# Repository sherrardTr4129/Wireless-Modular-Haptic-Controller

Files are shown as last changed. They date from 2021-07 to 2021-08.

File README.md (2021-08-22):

# Wireless-Modular-Haptic-Controller
A small, flexible and modular wireless haptic controller for mobile manipulator control. This project attempts to take the rudimentary controller design implemented [here](https://github.com/sherrardTr4129/RealSense-BNO055-Pose-Estimation), and add a more complex feature set. Multiple controllers can be used on the same mesh network to create more intuitive human-robot interfaces. Ultimately, the goal of this project is to create a configuration of controllers to provide dexterous control of a mobile manipulator system. 

## Demo Video
Have a look at the system in action! The video below shows a single controller being used for controlling the locobot base with adaptive scaling control. 

LoCoBot Control (https://www.youtube.com/watch?v=vkgRInzt20c)

## Single Controller Architecture
A given single controller offers much more sensing and actuation capability as compared to the controller design implemented [here](https://github.com/sherrardTr4129/RealSense-BNO055-Pose-Estimation). In this design, each controller acts as a node on a larger mesh network. This allows for ease of addition and subtraction of nodes from said network, depending on the desired HRI configuration. Each controller has the ability to deliver audio (including basic TTS) and vibrotactile feedback to the user. In addition, the controller still contains a BNO055 sensor to extract the orientation of the controller itself in three dimensional space. Each given controller also has two momentary push buttons for user input. Please see the figure below for a graphical depicition of the controller architecture. 

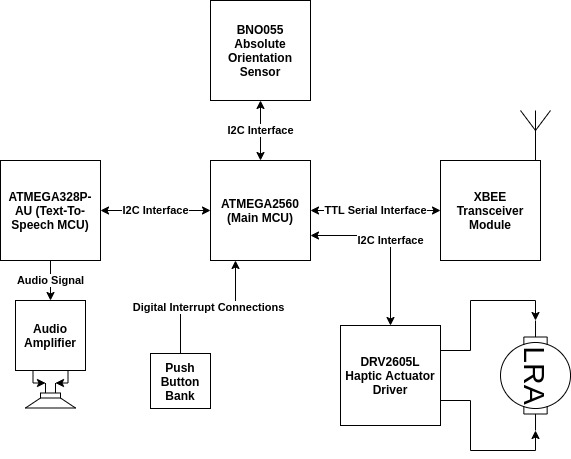
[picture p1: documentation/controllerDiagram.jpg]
Controller Architecture Diagram


The table below contains a more in-depth explaination of the individual controller architecture, including each sub-system's components.

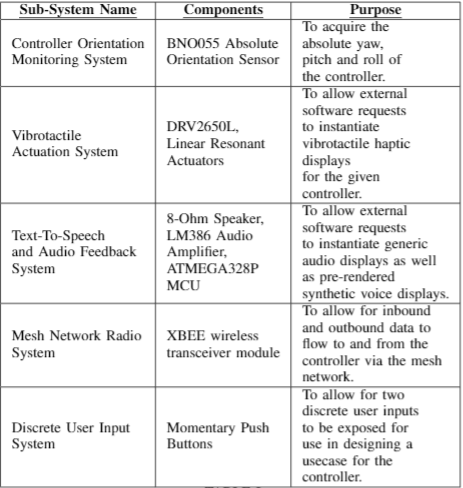
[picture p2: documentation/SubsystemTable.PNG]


The individual controller's firmware was designed using a split application level firmware and board support package (BSP) paradigm. All sensor and actuator control drivers were contained within the BSP and could be accessed from a BSP instance within the application level firmware. A graphical depiction of this software architecture can be seen within the figure below.

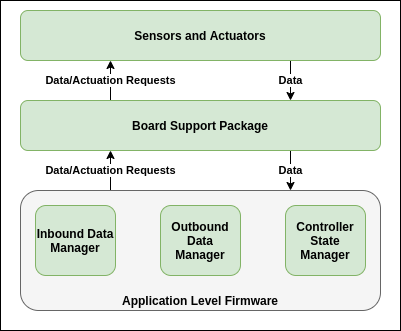
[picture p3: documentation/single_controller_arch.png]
Controller Software Architecture Diagram


Once the controller is completely assembled, it should look something like the controller in the figure below. 

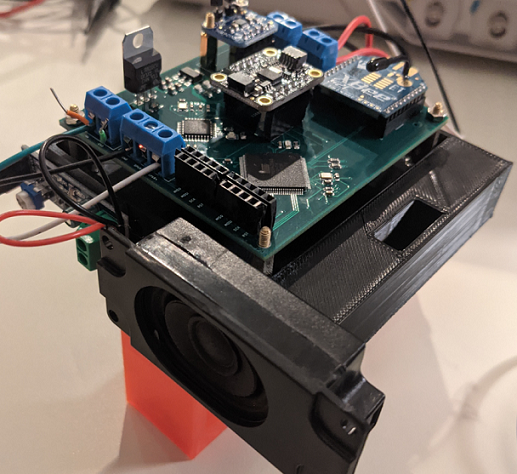
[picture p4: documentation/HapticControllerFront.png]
Controller Build


## High Level System Architecture
The system is comprised of a single base-station node, and several controller nodes. The base-station node serves as the entry point into the network and coordinates the setup of the overall mesh network (coordinator node). A ROS driver manages data transactions between the ROS infrastructure and the controller mesh network via a serial interface with the coordinator node. The mesh network itself is comprised of wireless XBee modules attached to each controller. These provide a high level of configurability for a relatively low price. Have a look at the data flow diagram below for a simplified explanation of the system's base configuration. 

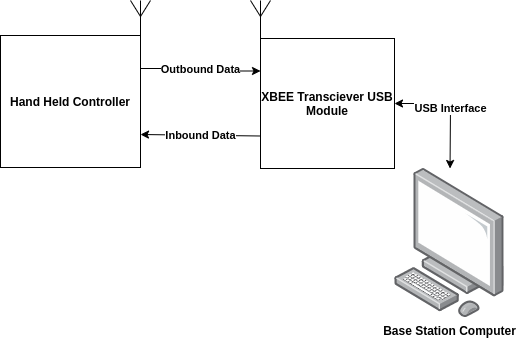
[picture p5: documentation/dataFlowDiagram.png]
Data Flow Diagram


A brief explanation of the inbound and outbound data types referenced in the above diagram can be seen in the table below.

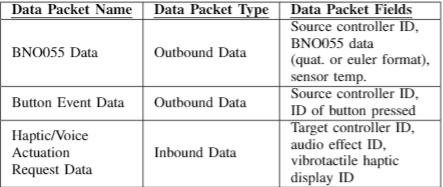
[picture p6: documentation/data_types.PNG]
Data Types


More controller nodes can be added to the network as needed based on the desired human-robot interface configuration. All data is transmitted in broadcast mode. That is, each node on the network will recieve data transmitted from any individual node. This was done to avoid having to set up direct addressing, and thus increasing the flexibility and ease of setup for the system. Data packets transmitted from a given node are formatted in JSON. One of the JSON fields in any given data packet format is the desired recipient of the data packet. This allows nodes on the network to quickly discern whether to process a given data packet or not using the aforementioned broadcast transmission mode.

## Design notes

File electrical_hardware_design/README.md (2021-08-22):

# Electrical Hardware Design
This sub-directory contains the KiCAD project used to generate the GERBERs needed to manufactor the PCB for the haptic controller. An overview of the PCB design and system BoM can be seen in the sections below.

## PCB Design
The PCB for the controller itself was attempted to be designed to be as modular as possible. For example, each of the sensors and actuators can be dynamically populated and de-populated based on the needs of the given controller within the HRI configuration being constructed. Please note that the PCB was designed with the assumption that it would be manufactored through the use of JLCPCB, so many of the surface mount components are chosen from their inventory system. A picture of the bare PCB can be seen in the image below. 

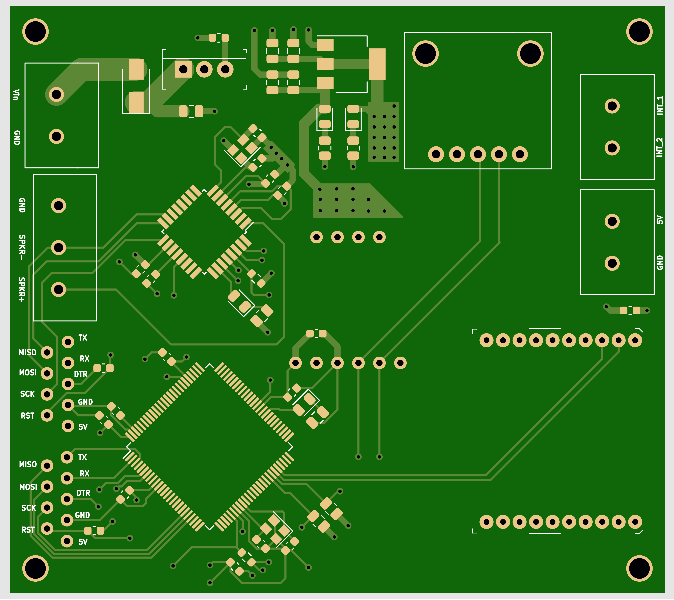
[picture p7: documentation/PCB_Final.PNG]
Bare PCB


The overall controller is powered off of a 9V battery, but can handle input voltages up to 12V. Some of the other electical charictoristics of the controller can be seen within the table in the figure below.

Electrical Charictoristics

## System Bill Of Materials
The overall bill of materials needed to build a single controller can be seen within the table below.

| Item | Vendor Link | Price Per Unit | Quantity  | Total Price |
|:---:|:---:|:---:|:---:|:---:|
| XBee Transceivers | [Link](https://www.digikey.com/en/products/detail/digi/XB24CZ7WIT-004/5322374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) | $27.93 | 1 | $27.93 |
| DRV2605L | [Link](https://www.adafruit.com/product/2305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) | $7.95 | 1 | $7.95 |
| ERM Pancake Motor | [Link](https://www.adafruit.com/product/1201) | $1.95 | 1 | $1.95 |
| 0.5W 8Ohm Speaker | [Link](https://www.sparkfun.com/products/15350) | $0.95 | 1 | $0.95 |
| Momentary Push Buttons (Pack Of 10) | [Link](https://www.amazon.com/weideer-Momentary-Self-Reset-Pre-soldered-R13-507-RBK-X/dp/B08SQQWJ5X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) | $1.00 | 1 | $1.00 |
| Stemma BNO055 Breakout | [Link](https://www.adafruit.com/product/4646) | $19.95 | 1 | $19.95 |
| PCB (populated) | N/A | $15 | 1 | $15 |
| L7805CV | [Link](https://www.amazon.com/L7805CV-Positive-Voltage-Regulator-Output/dp/B09B2D3T2F) | $0.40 | 1 | $0.40 |
| LM386 Breakout | [Link](https://www.amazon.com/gp/product/B01FDD3FYQ/ref=ppx_yo_dt_b_asin_title_o00_s00?ie=UTF8&psc=1) | $1.598 | 1 | $1.598 |
| Screw Terminals | [Link](https://www.amazon.com/gp/product/B07H5G7GC6/ref=ppx_yo_dt_b_asin_title_o09_s00?ie=UTF8&psc=1) | $0.17 | 4 | $0.67 |
| Misc Consumables (standoffs, pin headers) | N/A | $2 | 1 | $2 |
| | | | | |
| | | | Total Cost: | $79.39 |

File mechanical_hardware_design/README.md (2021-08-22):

# Mechanical Hardware Design
The mechanical designs for this project were designed under a modularity paradigm. That is, the base that the controller PCB is installed in is designed to be attached to a hand-held controller, haptic belt, or other mounting location depending on the desired HRI configuration. In addition to the controller base, a hand-held glove was also designed to allow for easy interfacing with the controller itself. The controller base and hand-held glove assembly (with push buttons installed) can be seen in the figure below.

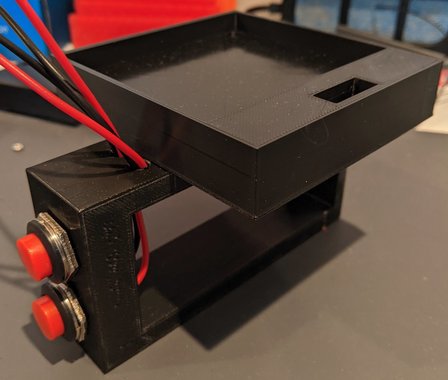
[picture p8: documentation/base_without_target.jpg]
Controller Assembly


The controller base is designed to allow for an optional vision target to be installed. This vision target will allow for the extraction of the controller's position in 3D space to be extracted through the use of a depth camera. Please have a look at the figure below depicting the controller base and hand-held glove assembly (with push buttons installed) along with the optional vision target.

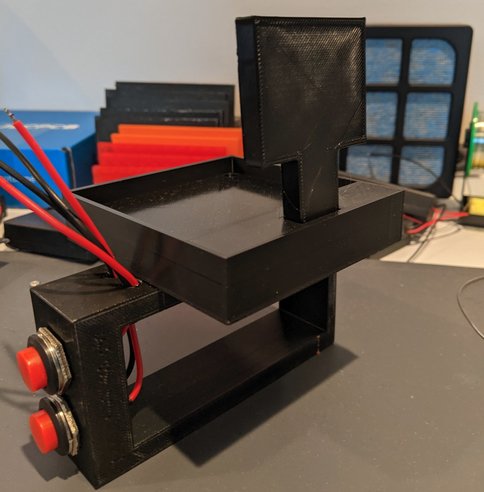
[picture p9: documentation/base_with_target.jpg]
Controller Assembly With Vision Target


The mechanical designs for these three aforementioned mechanical components can be found in the folders within the sub-directory as freeCAD documents. You can export the STL to 3D print these components from freeCAD.

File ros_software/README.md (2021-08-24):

# ROS Software
This sub-directory outlines the ROS software developed to showcase the capabilities of the modular haptic controller. In particular, this sub-directory includes a ROS driver for bi-directional interfacing with the controller network via standard ROS interfaces. It also included a ROS package that interfaces with said ROS driver to demonstrate the control of a robot base using the controller in its hand-held configuration. 

## Inbound and Outbound Data Packet JSON Formats
This sub-section outlines the JSON schema for the inbound and outbound data packets for a given controller on the controller mesh network.

### Outbound data JSON schema
The format of outbound BNO055 data packets can be seen below (if usingEuler is set to true):
```JSON
{
  "packet_type": "outbound_data",
  "controller_id": "right_hand",
  "euler_x": 0,
  "euler_y": 0,
  "euler_z": 0,
  "temp_c": 30
}
```

If usingEuler is set to false, the format of the outbound BNO055 data packet will be:
```JSON
{
  "packet_type": "outbound_data",
  "controller_id": "right_hand",
  "quat_x": 0,
  "quat_y": 0,
  "quat_z": 0,
  "quat_w": 0,
  "temp_c": 30
}
```

Note these are both just templates, and the value of a given field will change.

The other outbound data type from a given controller is event data packets. These are transmitted whenever user input is obtained through the pushbuttons attached to a given controller. The format of this type of data packet can be seen below:
```JSON
{
  "packet_type": "button_event",
  "controller_id": "right_hand",
  "event_type": "top_button_pressed"
}
```

### Inbound data JSON schema
Inbound JSON data packets contain a target controller, and a requested audio or haptic event to display to the user. These data packets take the form of the following JSON schema:

```JSON
{
  "controller_name": "right_hand",
  "voice_action_id": 1,
  "haptic_action_id": 53
}
```

More on the meanings of the values for the voice\_action\_id and haptic\_action\_id fields in the upcomming sections. The JSON seen above will be created within the ROS driver itself, so don't worry too much about this.

## ROS Coordinator Node Serial Driver
The haptic\_orientation\_capture\_driver ROS node serves as a bridge between the controller mesh network and a given ROS software architecture. This driver will manage the serial interfacing between a base-station coordinator XBee and the host computer. This driver will also publish recieved BNO055 data streams and button press events. This driver also exposes a ROS service that can be called by external ROS nodes to send audio-haptic event requests to a given controller on the mesh network. 

### Custom Messages
The packages outlined here make use of a few custom ROS messages to communicate between the ROS infrustructure and the controller mesh network. Please have a look at the table below for an outline of these messages.

| Message Name | Message Components |
|---|---|
| bno055_euler_data.msg | **Description** - BNO055 data received from mesh network is published to ROS infrastructure through this message (euler format) <br><br>**Message Content:**<br>string controller\_name - The controller the BNO055 data came from<br>Header header - header containing a timestamp<br>float64 roll - roll data (in degrees)<br>float64 pitch - pitch data (in degrees)<br>float64 yaw - yaw data (in degrees) |
| bno055_quat_data.msg | **Description** - BNO055 data received from mesh network is published to ROS infrastructure through this message (quaternion format)<br><br>**Message Content:**<br>string controller\_name - The controller the BNO055 data came from<br>geometry_msgs/QuaternionStamped quat - orientation data as quaternion |
| controller_event_data.msg | **Description** - button press event data received from mesh network is published to ROS infrastructure through this message<br><br>**Message Content:**<br>string controller\_name - The controller the button event data came from<br>Header header - header containing a timestamp<br>string event_type - string representation of which button was pressed on the controller |
| controller_haptic_voice.msg | **Description** - audio-haptic requests can be sent to a given controller on the mesh network via the ROS service described below. <br>This message is used to make said request.<br><br>**Message Content:**<br>string controller\_name - The controller the request is bound for<br>int16 haptic_action_id - selected haptic display ID<br>int16 voice_action_id - selected TTS display ID |

### Custom Service
The haptic\_orientation\_capture\_driver ROS node hosts a service that allows users to request an audio-haptic event to be performed by a given controller. This service call requires a haptic\_voice\_event message instance containing the voice\_action\_id and haptic\_action\_id for a given controller with name controller\_name. For the pre-rendered TTS events, please see firmware to determine mapping between voice\_action\_id and a given TTS event. For the haptic diplays, haptic\_action\_id should be chosen from the table below based on the desired waveform.

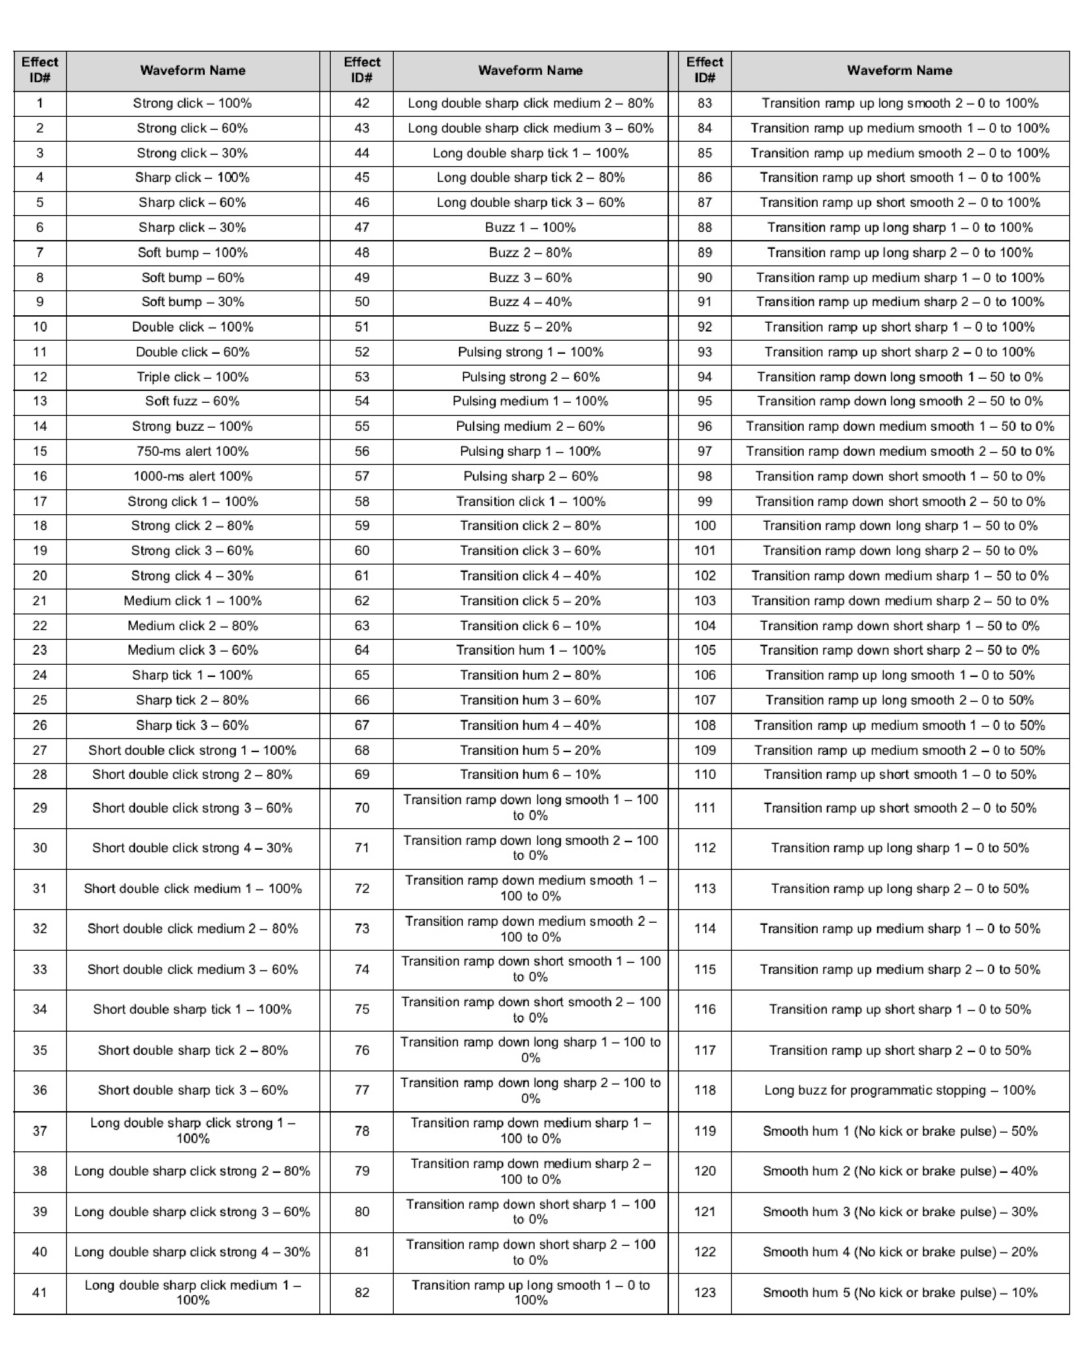
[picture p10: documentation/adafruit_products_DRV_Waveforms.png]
DRV2560 Waveforms


## LoCoBot Base Control Example
The locobot\_haptic\_control ROS package was developed to showcase the usefulness of the developed modular controller. This particular node makes use of all the data streams available from a controller, and can make audio-haptic requests based on custom conditions set by the user. Currently, the node allows for control of the robot base with adjustable scaling. The scaling mode can be changed through button press events on the controller. Please see the youtube video in this repositories base README.md file for an example of this working. Both the haptic\_orientation\_capture\_driver and the locobot\_haptic\_control ROS packages can be launched using the locobot\_haptic\_control.launch file in the locobot\_haptic\_control ROS package.

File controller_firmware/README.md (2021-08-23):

# Controller Firmware Design
This sub-directory contains the firmware developed for the two processors on the hand-held controller. Please see below for notes about each MCU's firmware and the procedure to flash the firmware onto each of the MCU's. 

## Firmware Dependencies 
This section will breifly outline the different firmware dependencies within this project. Please note that all firmware dependencies are obtainable through the arduino software manager. 

### Main Controller Firmware Dependencies
* **Adafruit Sensor Library** - This library provides general functionallity required for the two onboard adafruit sensors.
* **Adafruit BNO055 Library** - This library provides functionallity needed to read data from the onboard BNO055 sensor via an I2C interface. 
* **Adafruit DRV2605 Library** - This library provides functionallity needed to interface with the DRV2605 driver board via an I2C interface.
* **ArduinoJson** - This library provides JSON document construction functionallity and functionallity to serialize said documents via the XBee wireless interface. 

### Text-To-Speech Controller Firmware Dependencies
* **Talkie** - This library provides rudimentary TTS functionallity utilizing the onboard MCU TIMER1 and TIMER2 peripherals. 

## Main Controller Firmware
The main controller firmware is designed to run on the ATMEGA2560 processor on the PCB. Its main purpose is to actuate audio-haptic displays based on requests received by the basestation, and to transmit data from the onboard BNO055 sensor back to the basestation. Outside of the main\_controller\_firmware.ino file, two other software packages are provided. The first is the BSP, which provides functionallity required to initialize and manage all onboard actuators and sensors. The second is the inbound and outbound data stream managers. These classes are designed to unpack incomming request JSON packets from the basestation and package and serialize BNO055 data JSON packets respectively. 

For each controller on the network, two lines of code need to be examined and potentially changed at compile time within the main\_controller\_firmware.ino file. The first is:

```C
bool usingEuler = true;
```
This boolean flag will setup the BNO55 sensor in euler angle mode if true, and quaternion mode if false. The outbound JSON document will be set up differently depending on the state of this variable as well. The second line to examine is:

```C
const char* controller_name = "right_hand";
```
This line defines the given controller's name. The controller name is an important field in all inbound and outbound JSON packets. For outbound data, the controller\_name field is used to determine the origin of the recieved BNO055 data packet. For inbound data, the recieved data packet needs to have the controller\_name field value equivalent to the name set in the above line of code for it to be processed by a given controller. Please ajdust this line accordingly based on the desired HRI configuration.

## Text-To-Speech Controller Firmware
The Text-To-Speech controller firmware is designed to be run on the ATMEGA328P-AU processor on the PCB. It's main purpose is to accept requests to play pre-rendered TTS audio events via the I2C interface managed by the main controller. The I2C transaction is simple, as it requires a single integer number between 0 and 4 corresponding to one of the aforementioned TTS events. The TTS events are instantiated through the use of the Talkie library. If the included vocabularies within the Talkie library do not suit your needs, there are [tutorials](https://github.com/ptwz/python_wizard) on how to render new TTS events.

## Bootloader and Firmware Flashing Proceedure
The pins on the PCB itself needed to flash the bootloader and respective firmware can be seen highlighted in the image below:

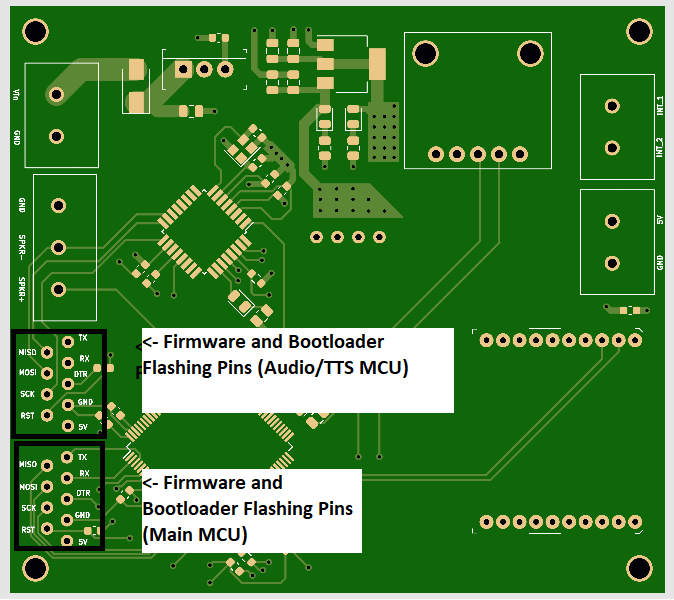
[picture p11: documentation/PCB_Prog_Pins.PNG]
MCU Bootloader and Firmware Flashing Pins


### Bootloader Flashing 
After assembling a new board mechanically and electrically, the appropriate bootloader needs to be flashed to each respective MCU. The easist way to do this is to use a seperate arduino uno as an ICSP device. Please follow the tutorial outlined [here](https://www.electronics-lab.com/project/installing-the-arduino-bootloader-on-the-atmega328p-microcontroller/) to flash the bootloader onto each respective MCU using an arduino uno as an ICSP. Please note that this tutorial assumes the target chip is an ATMEGA328P, which is true for the TTS MCU, but not for the main MCU. Make sure to change the board type to "ATmega2560" when flashing the bootloader to the main MCU.

### Firmware Flashing
To flash the firmware on each respective MCU, a USB->TTL Serial converter is required. I made use of the converter found [here](https://www.amazon.com/HiLetgo-FT232RL-Converter-Adapter-Breakout/dp/B00IJXZQ7C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) In my development efforts. In the case of either MCU, the connections between the USB->TTL Serial converter and the board need to be made as described below:

| Firmware Flashing Pin | USB<->TTL Serial Converter Pin |
|---|---|
| GND | GND |
| TX | RX |
| RX | TX |
| DTR | DTR (through 100nF capacitor)  |

Please make sure to change the programmer from "Arduino as ISP" used in the last step back to "AVRISP MKll" before trying to upload any firmware.

## XBee Radio Configuration
As mentioned previously, the controller XBees all need to be configured as routers, and the single base-station XBee needs to configured as a coordinator. In all cases, the devices should be set in broadcast mode. That is, if a packet is transmitted from an XBee radio, all other radios on the network should recieve it. There are several tutorials on XBee configuration using the XTCU tool. [Here](https://youtu.be/cf3RLBg4t5s) is one useful tutorial video.

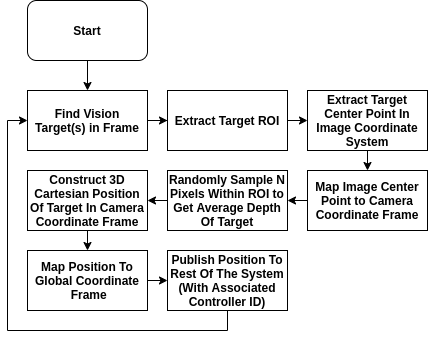
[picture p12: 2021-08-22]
documentation/coordinate_extraction_process.png

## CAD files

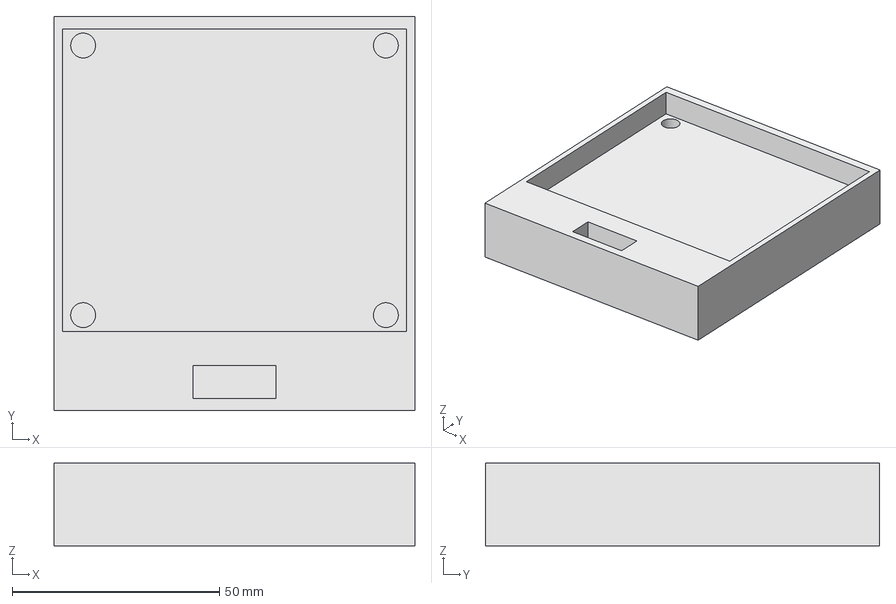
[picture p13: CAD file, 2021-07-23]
mechanical_hardware_design/controller_holder/controller_board_holder.FCStd
87.0 x 95.0 x 20.0 mm

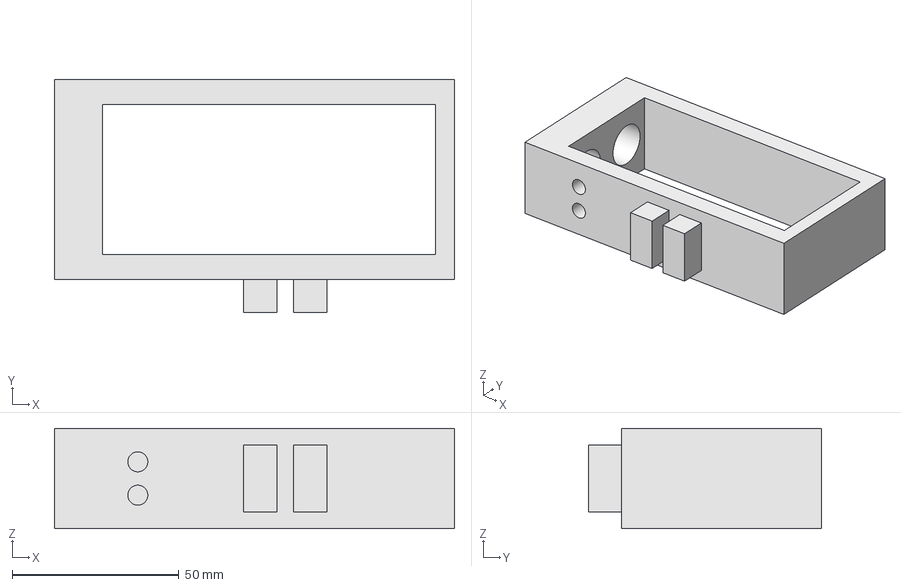
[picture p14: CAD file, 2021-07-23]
mechanical_hardware_design/hand_glove/hand_glove_base.FCStd
120.0 x 70.0 x 30.0 mm

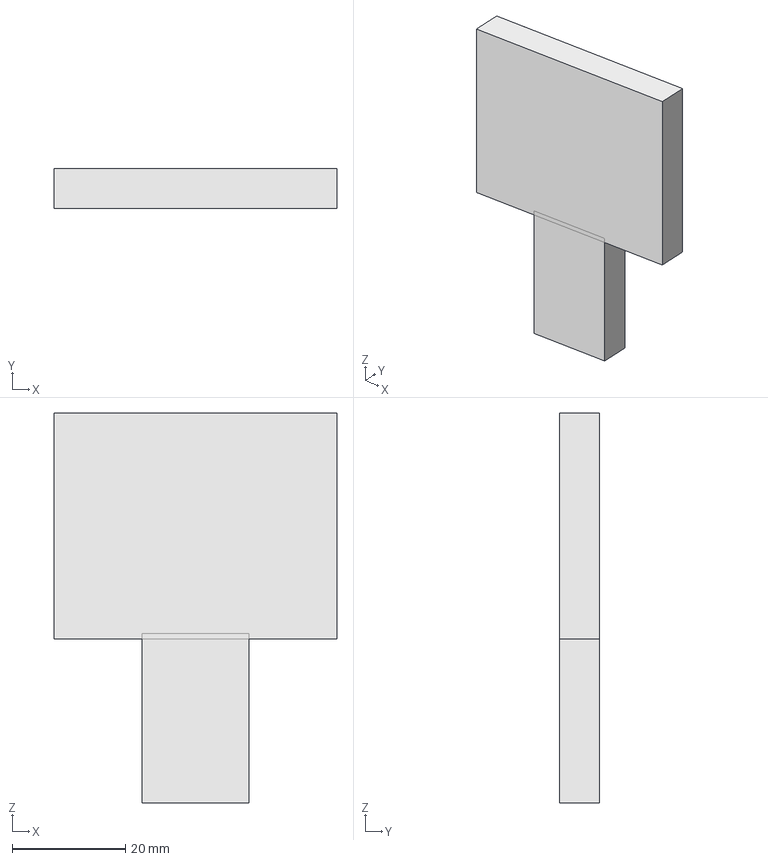
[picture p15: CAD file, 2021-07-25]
mechanical_hardware_design/vision_target/vision_target.FCStd
50.0 x 7.00 x 69.0 mm

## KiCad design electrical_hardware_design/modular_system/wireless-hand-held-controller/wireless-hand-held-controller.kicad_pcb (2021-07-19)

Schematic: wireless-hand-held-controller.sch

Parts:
C1, C4: 4.7u; C_0805_2012Metric; LCSC C1779
C2: 330n; C_0805_2012Metric; LCSC C1740
C3, C7: 1u; C_0805_2012Metric; LCSC C28323
C5, C6, C8, C9, C10, C13, C16, C17, C18, C19, C20, C21, C22, C23, C24: 100n; C_0603_1608Metric; LCSC C14663
C11, C12, C14, C15: 15p; C_0603_1608Metric; LCSC C1644
D1: D_Small; D_SMA; LCSC C95872
D2, D3, D4, D5: LED; LED_0805_2012Metric; LCSC C84256
J1: 328P_Prog_Pins; fivePinConn
J2: 328P_Bootloader_Pins; fourPinConn
J3: Input Power; 2-pinScrewTerm
J4: 2560_Prog_Pins; fivePinConn
J5: 2560_Bootloader_Pins; fourPinConn
J6: Speaker Conn; 3-pinScrewTerminal
J7: INT_PWR_CON; 2-pinScrewTerm
J8: External_Interrupts; 2-pinScrewTerm
MOD1: XB24CZ7WIT-004; XBEE-20_THT; MPN XB24CZ7WIT-004; Digi-Key_PN 602-1560-ND
Q1, Q2: BSS138; SOT-23-3; MPN BSS138; Digi-Key_PN BSS138CT-ND
R1, R3, R4, R6, R7, R8: 4.7k; R_0805_2012Metric; LCSC C17673
R2, R5: 10k; R_0603_1608Metric; LCSC C25804
R9, R10, R11, R12: 10k; R_1206_3216Metric; LCSC C17902
U1: L7805CV; TO-220-3; MPN L7805CV; Digi-Key_PN 497-1443-5-ND
U2: AMS1117-3.3; SOT-223-3_TabPin2; LCSC C6186
U3: ATmega328P-AU; TQFP-32_7x7mm_P0.8mm; LCSC C14877
U4: ATmega2560-16AU; TQFP-100_14x14mm_P0.5mm; LCSC C22460
U5: StemmaBNO055
U6: DRV2605L
Y1, Y2: 16Mhz; Crystal_SMD_2520-4Pin_2.5x2.0mm; LCSC C284159

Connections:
328P_MISO_CON: J2.4, U3.16 (PB4)
328P_MOSI_CON: J2.3, J6.2, U3.15 (PB3)
328P_RESET_CON: C13.1, J2.1, R2.1, U3.29 (~RESET~/PC6)
328P_RX_CON: J1.4, U3.30 (PD0)
328P_SCK_CON: J2.2, U3.17 (PB5)
328P_TX_CON: J1.5, U3.31 (PD1)
328P_XTAL1_CON: C11.1, U3.7 (XTAL1/PB6), Y1.1
328P_XTAL2_CON: C12.1, U3.8 (XTAL2/PB7), Y1.3
2560_MISO_CON: J5.4, U4.22 (PB3)
2560_MOSI_CON: J5.3, U4.21 (PB2)
2560_RESET_CON: C17.1, J5.1, R5.1, U4.30 (~RESET)
2560_RX_CON: J4.4, U4.2 (PE0)
2560_SCK_CON: J5.2, U4.20 (PB1)
2560_SCL_CON: R8.2, U3.28 (PC5), U4.43 (PD0), U5.4 (SCL), U6.3 (SCL)
2560_SDA_CON: R6.2, U3.27 (PC4), U4.44 (PD1), U5.5 (SDA), U6.4 (SDA)
2560_TX_CON: J4.5, U4.3 (PE1)
2560_XTAL1_CON: C14.1, U4.34 (XTAL1), Y2.1
2560_XTAL2_CON: C15.1, U4.33 (XTAL2), Y2.3
+3V3: C4.1, C7.1, C23.1, D3.2 (A), MOD1.1 (Vcc), Q1.1, Q2.1, R9.2, R10.2, U2.2 (VO)
+5V: C1.1, C3.1, C5.1, C8.1, C9.1, C10.1, C18.1, C19.1, C20.1, C21.1, C22.1, C24.2, D2.2 (A), J1.1, J4.1, J7.2, R2.2, R5.2, R6.1, R8.1, R11.2, R12.2, U1.3 (OUT), U2.3 (VI), U3.4 (VCC), U3.6 (VCC), U3.18 (AVCC), U4.10 (VCC), U4.31 (VCC), U4.61 (VCC), U4.80 (VCC), U4.100 (AVCC), U5.1 (Vin), U6.1 (Vin)
+BATT: C2.1, D1.1 (K), U1.1 (IN)
GND: C1.2, C2.2, C3.2, C4.2, C5.2, C6.2, C7.2, C8.2, C9.2, C10.2, C11.2, C12.2, C14.2, C15.2, C16.2, C18.2, C19.2, C20.2, C21.2, C22.2, C23.2, C24.1, J1.2, J3.1, J4.2, J6.3, J7.1, MOD1.10 (GND), R1.1, R3.1, R4.1, R7.1, U1.2 (GND), U2.1 (GND), U3.3 (GND), U3.5 (GND), U3.21 (GND), U4.11 (GND), U4.32 (GND), U4.62 (GND), U4.81 (GND), U4.99 (GND), U5.3 (GND), U6.2 (GND), Y1.2, Y1.4, Y2.2, Y2.4
INT1_CON: J8.2, U4.6 (PE4)
INT2_CON: J8.1, U4.7 (PE5)
unnamed: C6.1, U3.20 (AREF)
unnamed: C13.2, J1.3
unnamed: C16.1, U4.98 (AREF)
unnamed: C17.2, J4.3
unnamed: D1.2 (A), J3.2
unnamed: D2.1 (K), R1.2
unnamed: D3.1 (K), R3.2
unnamed: D4.1 (K), R4.2
unnamed: D5.1 (K), R7.2
unnamed: D5.2 (A), U4.59 (PC6)
SPKR_NON_INVERTING: J6.1, U3.1 (PD3)
TALKING_STATUS: D4.2 (A), U3.26 (PC3)
XBEE_RX_3.3V: MOD1.3 (DIN/~Config), Q1.2, R10.1
XBEE_RX_5V: Q1.3, R11.1, U4.46 (PD3)
XBEE_TX_3.3V: MOD1.2 (DOUT), Q2.2, R9.1
XBEE_TX_5V: Q2.3, R12.1, U4.45 (PD2)

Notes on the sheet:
ATMEGA328P-AU programming connections
ATMEGA328P-AU MCU Oscillator
Indicator LEDs
input power
Power Rail Regulation
ATMEGA2560 Programming/Bootloader Flash
ATMEGA2560 MCU Oscillator
ATMEGA328P-AU MCU
i2c bus
BNO055 Sensor
DRV2605L Haptic Driver
XBEE
Connections For External Interrupts
XBEE Level Shifting

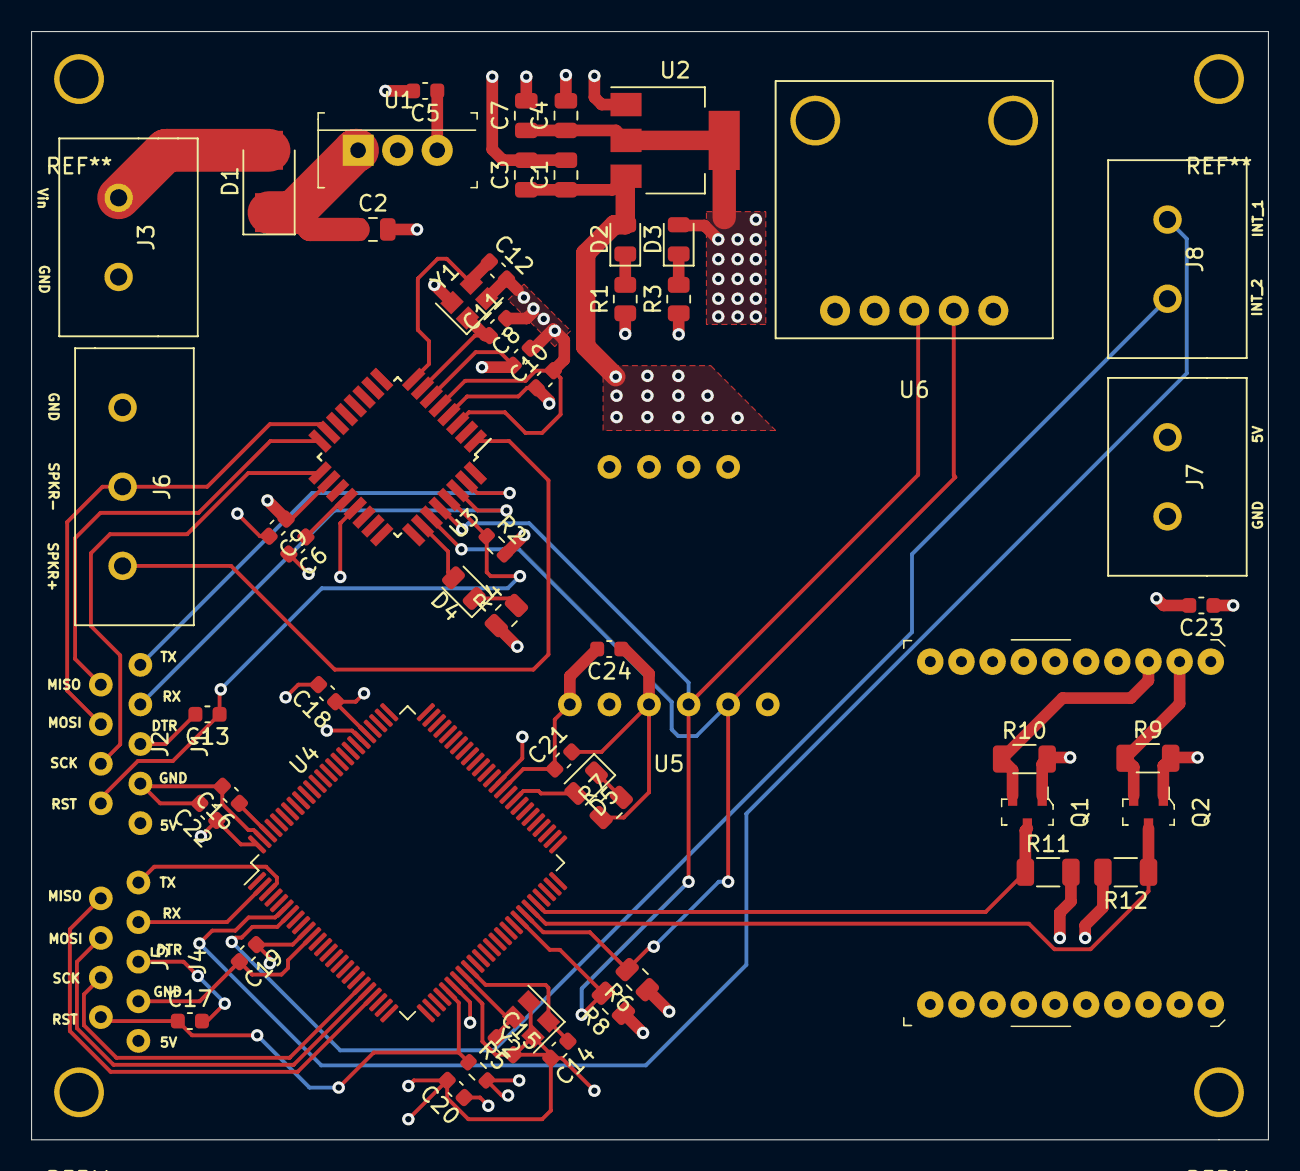
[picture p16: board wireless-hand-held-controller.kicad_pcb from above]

Board: 4 copper layers, 79.4 x 71.1 mm, 60 parts (0 on the bottom side), 40 nets.

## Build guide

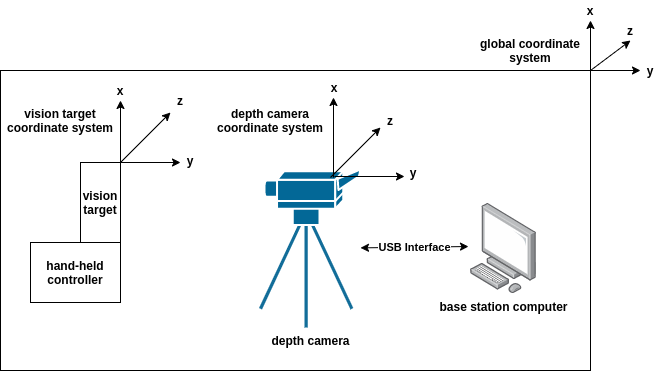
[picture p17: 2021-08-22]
documentation/cartesian_extraction_setup.png

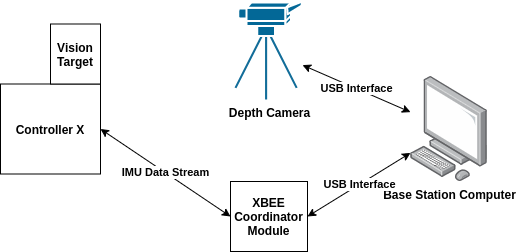
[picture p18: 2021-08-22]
documentation/dataFusionSetup.png

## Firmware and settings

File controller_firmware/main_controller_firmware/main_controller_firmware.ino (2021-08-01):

/*
   Author: Trevor Sherrard
   Since: July 23, 2021
   Purpose: firmware for main MCU on wireless
            haptic controller.
*/
// include libraries needed for peripherals
#include <Wire.h>
#include <Adafruit_Sensor.h>
#include <Adafruit_BNO055.h>
#include <utility/imumaths.h>
#include <Adafruit_DRV2605.h>
#include <ArduinoJson.h>

// include system libraries
#include "include/system_config.h"
#include "include/bsp.h"
#include "include/outbound_json_manager.h"
#include "include/inbound_json_manager.h"

// create adafruit BNO055 sensor handle
Adafruit_BNO055 bno = Adafruit_BNO055(-1, BNO_I2C_ADDR);

// create DRV2605 instance
Adafruit_DRV2605 drv;

// create bsp instance
hapticBSP bsp = hapticBSP(&bno, &drv);

// define global variables for sensor state data
bool is_BNO055_start;
bool is_DRV2605_start;

// define global variables for BNO055 Data
float euler_x, euler_y, euler_z;
int8_t temp;

// define flags for ISRs
bool was_in_top_button_ISR = false;
bool was_in_bottom_button_ISR = false;

// define outbound JSON doc manager
bool usingEuler = true;
const char* controller_name = "right_hand";
OutboundJsonDocManager outbound_doc = OutboundJsonDocManager(usingEuler, controller_name);

// define inbound JSON doc manager
InboundJsonDocManager inbound_doc = InboundJsonDocManager(controller_name);
String inbound_data_str;
char inbound_data[INBOUND_BUFFER_SIZE];

// define button ISRs and debounce timers
static unsigned long last_top_interrupt_time = 0;
static unsigned long last_bottom_interrupt_time = 0;
unsigned long cur_top_interrupt_time;
unsigned long cur_bottom_interrupt_time;

void top_button_ISR()
{
  // only allow interrupt to fire if it's been long than
  // MIN_MS_BETWEEN_INT since last interrupt
  cur_top_interrupt_time = millis();
  if (cur_top_interrupt_time - last_top_interrupt_time > MIN_MS_BETWEEN_INT)
  {
    was_in_top_button_ISR = true;
  }
  last_top_interrupt_time = cur_top_interrupt_time;
}

void bottom_button_ISR()
{
  // only allow interrupt to fire if it's been long than
  // MIN_MS_BETWEEN_INT since last interrupt
  cur_bottom_interrupt_time = millis();
  if (cur_bottom_interrupt_time - last_bottom_interrupt_time > MIN_MS_BETWEEN_INT)
  {
    was_in_bottom_button_ISR = true;
  }
  last_bottom_interrupt_time = cur_bottom_interrupt_time;
}

void setup() {
  // set up serial communication
  Serial.begin(MAIN_SERIAL_BAUD);
  Serial1.begin(XBEE_SERIAL_BAUD);

  // start bsp components
  is_BNO055_start = bsp.startBNO055();
  is_DRV2605_start = bsp.startDRV2605();
  bsp.setup_tts_i2c();

  // init interrupt timer val
  cur_top_interrupt_time = millis();
  cur_bottom_interrupt_time = millis();

  // setup up interrupt pins
  pinMode(INTERRUPT_PIN_1, INPUT_PULLUP);
  pinMode(INTERRUPT_PIN_2, INPUT_PULLUP);

  // attach ISR's to pins
  attachInterrupt(digitalPinToInterrupt(INTERRUPT_PIN_1), top_button_ISR, FALLING);
  attachInterrupt(digitalPinToInterrupt(INTERRUPT_PIN_2), bottom_button_ISR, FALLING);
}

void loop() {
  // address ISR flags if they are raised
  if (was_in_bottom_button_ISR)
  {
    // update doc with event info and serialize
    outbound_doc.bottomButtonEvent();
    outbound_doc.sendEventDoc();

    // play haptic effect and TTS
    bsp.playEffect(STRONG_RAMP);
    bsp.speak_tts(COURSE_SCALING);

    // reset flag
    was_in_bottom_button_ISR = false;
  }

  if (was_in_top_button_ISR)
  {
    // update doc with event info and serialize
    outbound_doc.topButtonEvent();
    outbound_doc.sendEventDoc();

    // play haptic effect and TTS
    bsp.playEffect(STRONG_RAMP);
    bsp.speak_tts(FINE_SCALING);

    // reset flag
    was_in_top_button_ISR = false;
  }

  // see if we have new incoming data from the Xbee
  Serial1.available();
  if (Serial1.available() > 0)
  {
    // if so, read the data from Serial1
    inbound_data_str = Serial1.readString();

    // move string to char array
    inbound_data_str.toCharArray(inbound_data, INBOUND_BUFFER_SIZE);

    // try to parse new data
    bool isParsed = inbound_doc.procInboundDoc(inbound_data);

    // extract values from object
    if (isParsed)
    {
      int voiceVal = inbound_doc.getVoiceActionID();
      int hapticVal = inbound_doc.getHapticActionID();

      // if hapticVal or voiceVal are non-zero, perform
      // respective audio or haptic display
      if (hapticVal >= 0)
      {
        bsp.playEffect(hapticVal);
      }

      if (voiceVal >= 0)
      {
        bsp.speak_tts(voiceVal);
      }
    }
  }

  // read from BNO055 sensor
  bsp.readEuler(euler_x, euler_y, euler_z);
  bsp.readTemp(temp);

  outbound_doc.updateEuler(euler_x, euler_y, euler_z);
  outbound_doc.updateTemp(temp);
  outbound_doc.sendDataDoc();

  delay(BNO_LOOP_DELAY);
}

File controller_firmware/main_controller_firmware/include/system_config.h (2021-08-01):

#ifndef SYS_CONFIG
#define SYS_CONFIG

// define interrupt pins
#define INTERRUPT_PIN_1		2
#define INTERRUPT_PIN_2		3
#define MIN_MS_BETWEEN_INT	300

// define BNO055 constants
#define BNO_I2C_ADDR		0x28
#define BNO_STARTUP_DELAY_MS	250
#define BNO_LOOP_DELAY		100

//define Serial parameters
#define MAIN_SERIAL_BAUD	115200
#define XBEE_SERIAL_BAUD	9600

// define DRV2605 parameters
#define EFFECT_DELAY		100
#define MAX_HAPTIC_EFFECT	117
#define PULSE_STRONG		52
#define CLICK_STRONG		17
#define BUZZ_STRONG		14
#define ONE_SEC_ALERT		16
#define SMOOTH_MEDIUM_RAMP	85
#define STRONG_RAMP		58

// define enum for TTS control
enum tts_control 
{
	ARM_TOO_LOW,
	ARM_TOO_HIGH,
	COLLISION_CLOSE,
	COURSE_SCALING,
	FINE_SCALING,
	MAX_TTS_ENUM_VAL
};

#define TTS_I2C_ADDR		8

#endif

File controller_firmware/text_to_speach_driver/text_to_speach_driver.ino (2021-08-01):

/*
   Author: Trevor Sherrard
   Since: July 25, 2021
   Purpose: This file contains the code required
            to manage and drive the onboard controller
            speaker.
*/

// include TTS and peripheral libraries
#include "Talkie.h"
#include "Vocab_US_Large.h"
#include "Vocab_Special.h"
#include "Vocab_US_TI99.h"
#include <Wire.h>

// include system libraries
#include "include/system_config.h"
#include "include/speech_driver.h"

// create speech driver object
Talkie talkie;
speechDriver spk_drv(&talkie);

// create callback for i2c events
void handle_i2c_event()
{
  // read control byte
  int rx_byte = Wire.read();

  // switch on byte, execute proper event
  switch (rx_byte)
  {
    case 0:
      spk_drv.arm_too_low();
      break;
    case 1:
      spk_drv.arm_too_high();
      break;
    case 2:
      spk_drv.obstacle_close();
      break;
    case 3:
      spk_drv.course_instructions();
      break;
    case 4:
      spk_drv.fine_instructions();
      break;
    default:
      break;
  }
}

void setup() {
  Wire.begin(I2C_ADDR); // join i2c bus
  Wire.onReceive(handle_i2c_event);
}

void loop() {
  delay(SPK_LOOP_REFRESH);
}

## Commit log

2021-07-12 add modular design
    [wireless-hand-held-controller.kicad_pcb, wireless-hand-held-controller.sch]
2021-07-12 add updated schematic file
    [wireless-hand-held-controller.sch]
2021-07-12 fix broken footprint import
    [wireless-hand-held-controller.sch]
2021-07-19 add logic level shifters for xbee
    [wireless-hand-held-controller.kicad_pcb, wireless-hand-held-controller.sch]
2021-07-23 add new mechanical models
    [controller_board_holder.FCStd, hand_glove_base.FCStd]
2021-07-25 add vision target model
    [vision_target.FCStd]
2021-07-25 inital commit of ROS driver software
    [box.urdf]
2021-07-26 add i2c support for TTS processor
2021-07-27 reimplement driver as class structure
2021-07-27 add interrupt debouncing
2021-07-28 fix incorrect baud rate
    [system_config.h]
2021-07-28 add handling of button press events
2021-08-01 swap button events, extend angle range
2021-08-24 remove LiDAR bringup, add in base-station driver
